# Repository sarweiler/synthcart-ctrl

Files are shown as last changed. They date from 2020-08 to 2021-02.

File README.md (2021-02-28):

# Synthcart Ctrl

Synthcart Ctrl is a controller for the Atari 2600 synthesizer [Synthcart](http://www.qotile.net/synth.html) by Paul Slocum. It's basically two Atari keyboard controller circuits on a single PCB.

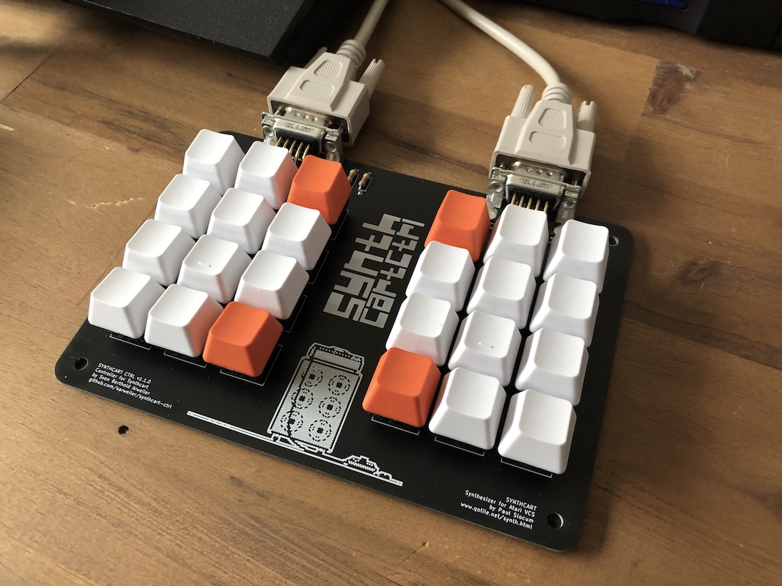
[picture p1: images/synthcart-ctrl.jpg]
Synthcart Ctrl


## Building Synthcart Ctrl

Building a Synthcart Ctrl is a very easy and beginner-friendly soldering project.

### PCB

Download the [synthcart-ctrl-gerbers.zip](https://github.com/sarweiler/synthcart-ctrl/releases/latest/download/synthcart-ctrl-gerbers.zip) file for the latest release, upload the zip archive to a PCB manufacturer of your choice, and order a PCB. Usually the default settings for the PCBs are okay – just choose a color for the solder mask that you like, if you dont want the standard PCB-green.

### Parts

* Four 4.7kOhm resistors.
* 24 Cherry MX switches of your choice, preferably of the PCB-mount variant (with fixation pins, [these, for example](https://www.mouser.com/ProductDetail/540-MX1A-11NW)). Non-PCB-mount switches (frame mount, without fixation pins) will work, too, but you will have to be careful to align them correctly when soldering.
* Two female DB9 connectors of the PCB-mount variant with mounting pins ([these](https://www.mouser.com/ProductDetail/571-2311765-1), [these](https://www.reichelt.de/d-sub-buchse-9-polig-gewinkelt-rm-9-4-gedr-d-sub-bu-09gwc-p113921.html), or any connector with similar measurements will work).
* 24 Cherry MX compatible keycaps of your choice. (I used [these](https://www.aliexpress.com/item/32987364794.html?spm=a2g0s.9042311.0.0.27424c4dBs286T) in the "blank" variant.)
* Two DB9 extension cables for connecting the controller to the Atari.
* 4 rubber feet

### Soldering

* Start by soldering the four 4.7k resistors.
* Solder the two female DB9 connectors.
* Solder all 24 Cherry MX switches. If you're using non-PCB-mount switches be careful to align them correctly.
* Install your keycaps on the switches.
* Add the rubber feet to the bottom of the PCB to avoid shorts when using the controller on conductive surfaces.
* Done!

## Using Synthcart Ctrl

Using the controller is pretty straight forward: Connect the left port of your controller to the left joystick port on the Atari and the right port to the right joystick port on the Atari using two DB9 extension cables.

Use the two sides of the controller like you would use two Atari keyboard controllers to control Synthcart.

For information on how to use Synthcart, check out the [Synthcart](http://www.qotile.net/synth.html) manual.

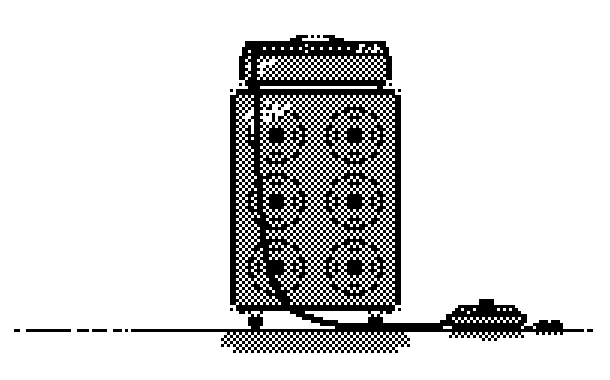
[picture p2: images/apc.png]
pcb artwork


## Disclaimer

Build and use Synthcart Ctrl at your own risk. I cannot be held responsible for damage caused to your devices, yourself or others.

## License

This work is licensed under [CC-BY-SA 4.0](http://creativecommons.org/licenses/by-sa/4.0/).



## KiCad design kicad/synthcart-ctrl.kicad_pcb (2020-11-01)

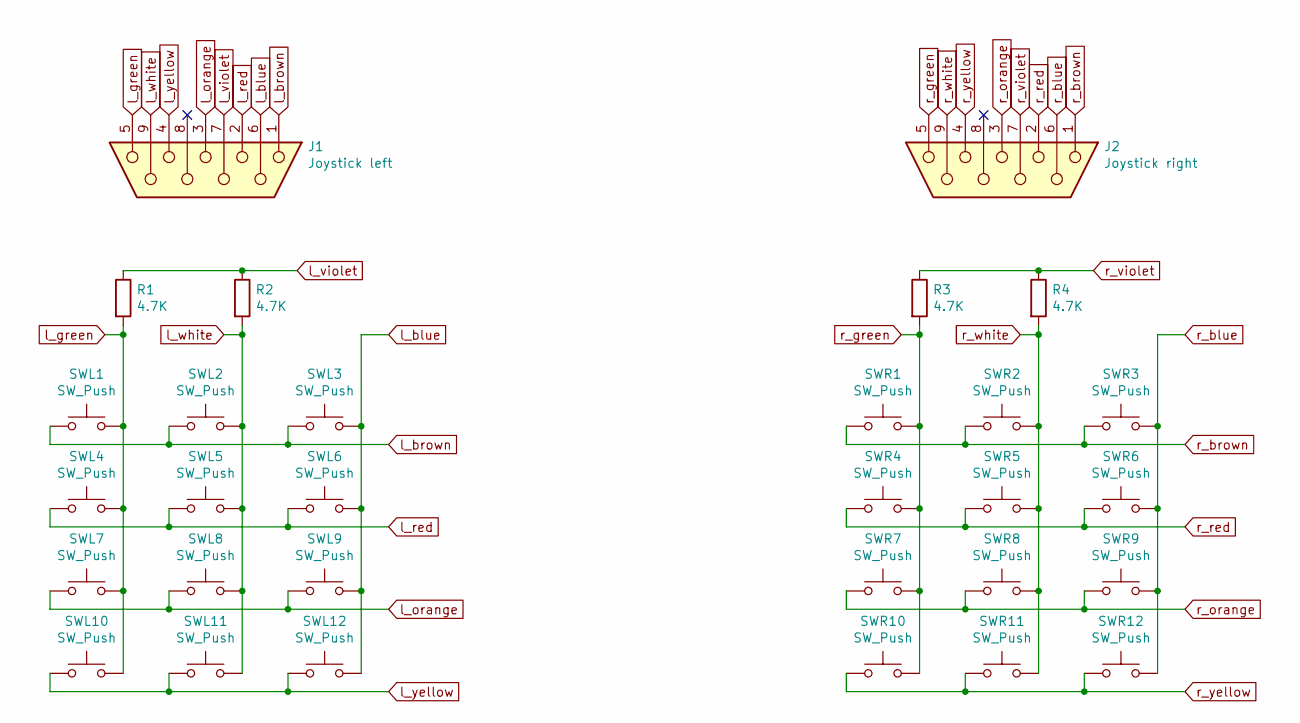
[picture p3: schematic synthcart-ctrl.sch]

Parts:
J1: Joystick left; DSUB-9_Female_Horizontal_P2.77x2.84mm_EdgePinOffset9.90mm_H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
J2: Joystick right; DSUB-9_Female_Horizontal_P2.77x2.84mm_EdgePinOffset9.90mm_H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
R1, R2, R3, R4: 4.7K; R_Axial_DIN0207_L6.3mm_D2.5mm_P10.16mm_Horizontal
SWL1, SWL2, SWL3, SWL4, SWL5, SWL6, SWL7, SWL8, SWL9, SWL10, SWL11, SWL12: SW_Push; SW_Cherry_MX_1.00u_PCB
SWR1, SWR2, SWR3, SWR4, SWR5, SWR6, SWR7, SWR8, SWR9, SWR10, SWR11, SWR12: SW_Push; SW_Cherry_MX_1.00u_PCB

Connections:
l_blue: J1.6, SWL3.2, SWL6.2, SWL9.2, SWL12.2
l_brown: J1.1, SWL1.1, SWL2.1, SWL3.1
l_green: J1.5, R1.2, SWL1.2, SWL4.2, SWL7.2, SWL10.2; also elsewhere on the board
l_orange: J1.3, SWL7.1, SWL8.1, SWL9.1
l_red: J1.2, SWL4.1, SWL5.1, SWL6.1
l_violet: J1.7, R1.1, R2.1; also elsewhere on the board
l_white: J1.9, R2.2, SWL2.2, SWL5.2, SWL8.2, SWL11.2
l_yellow: J1.4, SWL10.1, SWL11.1, SWL12.1
r_blue: J2.6, SWR3.2, SWR6.2, SWR9.2, SWR12.2
r_brown: J2.1, SWR1.1, SWR2.1, SWR3.1
r_green: J2.5, R3.2, SWR1.2, SWR4.2, SWR7.2, SWR10.2
r_orange: J2.3, SWR7.1, SWR8.1, SWR9.1
r_red: J2.2, SWR4.1, SWR5.1, SWR6.1
r_violet: J2.7, R3.1, R4.1
r_white: J2.9, R4.2, SWR2.2, SWR5.2, SWR8.2, SWR11.2
r_yellow: J2.4, SWR10.1, SWR11.1, SWR12.1

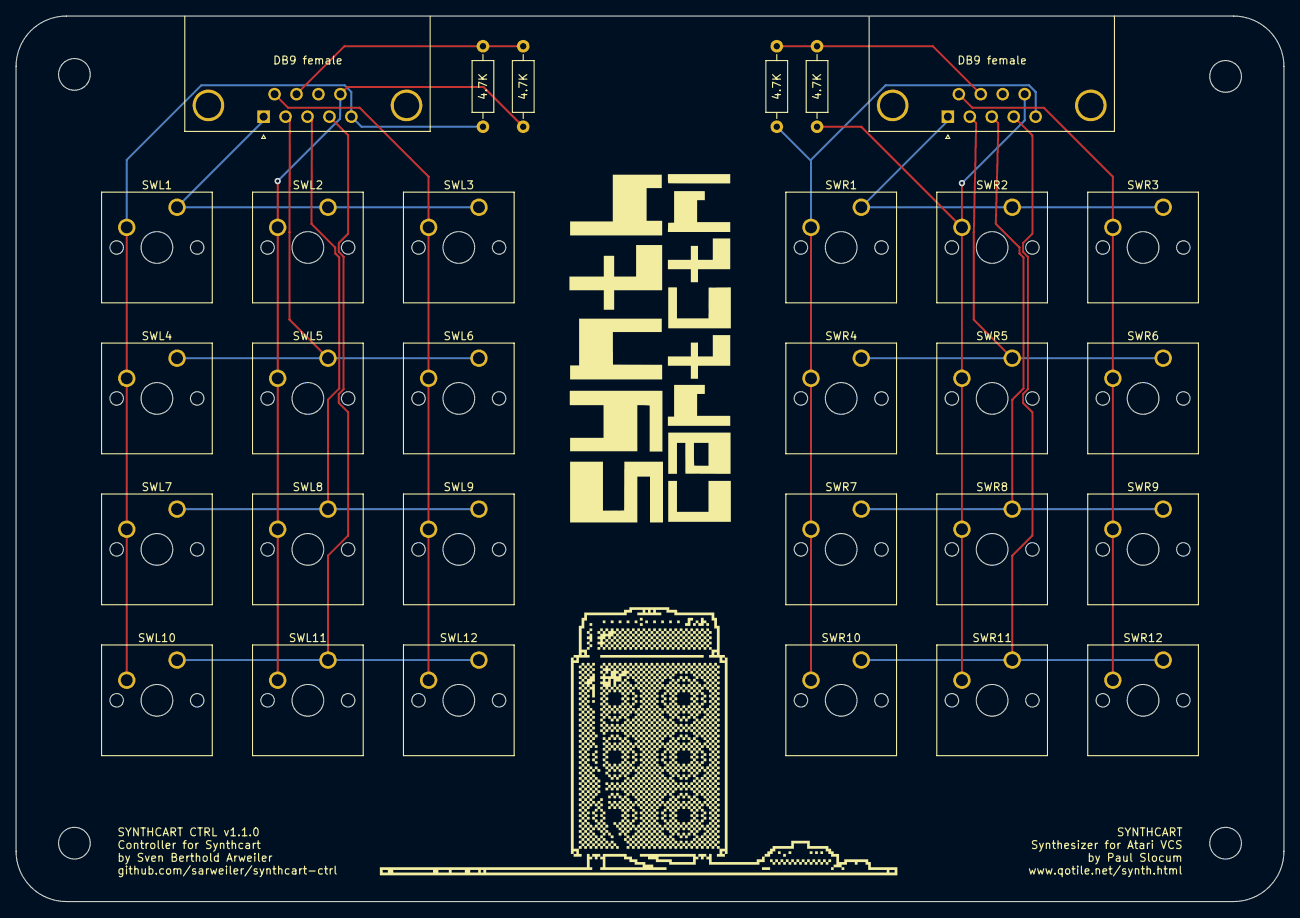
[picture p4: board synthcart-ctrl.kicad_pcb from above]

Board: 2 copper layers, 160.0 x 111.8 mm, 30 parts (0 on the bottom side), 16 nets.

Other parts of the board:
Re: 4.7K; R_Axial_DIN0207_L6.3mm_D2.5mm_P10.16mm_Horizontal

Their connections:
l_green: Re.2; also elsewhere on the board
l_violet: Re.1; also elsewhere on the board

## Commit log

2020-08-27 add Kicad files
    [synthcart-ctrl-B_Cu.gbr, synthcart-ctrl-B_Mask.gbr, synthcart-ctrl-B_Paste.gbr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]
2020-08-27 add PCB artwork to README
2020-08-28 update README with link to gerbers.zip for the latest release
2020-11-01 version 1.1.0 changes
    - move resisitors for left DB9 port to the right of the port
    - add 4mm mounting holes
    - pixel art without dithering
    [synthcart-ctrl-B_Cu.gbr, synthcart-ctrl-B_Mask.gbr, synthcart-ctrl-B_Paste.gbr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]
